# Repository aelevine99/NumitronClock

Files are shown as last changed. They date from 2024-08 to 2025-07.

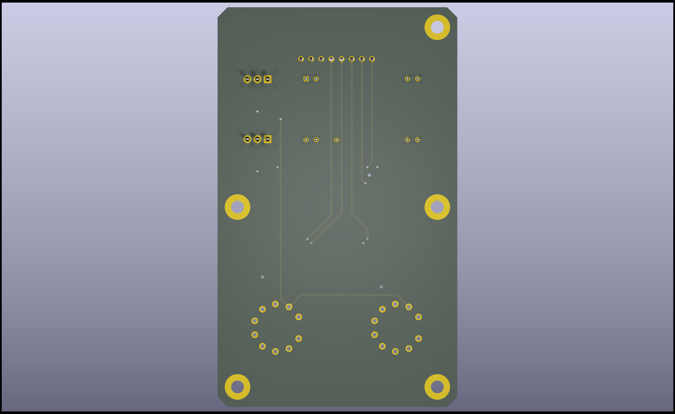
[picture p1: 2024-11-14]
numitron breakout/render_bot.png

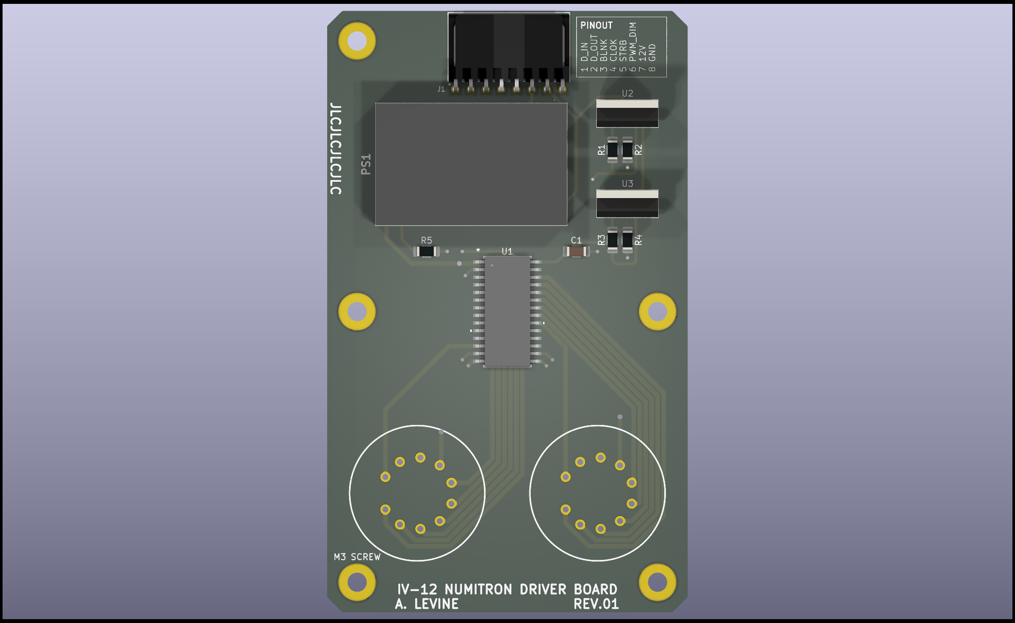
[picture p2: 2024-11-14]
numitron breakout/render_top.png

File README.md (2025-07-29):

# NumitronClock

## Project Overview
This project uses soviet IV-12 tubes (they were easier to find than actual Numitrons) for a fun, retro-inspired desk clock. The project is split into two main parts for modularity: a breakout board that can drive 2 tubes, and a control board with 2 outputs for breakout boards. I will update this description and provide documentation as the project evolves.

## NUMITRONS!
Advert for RCA NUMITRON Display Devices.
"Advert for RCA NUMITRON Display Devices". Electronic Design. 22 (12). Hayden: 163. 1974-06-07.

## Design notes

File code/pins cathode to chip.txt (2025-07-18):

---NUMBER TO PIN MAPPING---
Number	P1	P5	P6	P7	P8	P9	P10
1		0	0	1	1	0	0	0
2		1	1	0	1	1	0	0
3		0	1	1	1	1	1	0
4		0	0	1	1	0	1	1
5		0	1	1	0	1	1	1
6		1	1	1	0	1	1	1
7		0	0	1	1	1	0	0
8		1	1	1	1	1	1	1
9		0	1	1	1	1	1	1
0		1	1	1	1	1	0	1
A		1	0	1	1	1	1	1
b		1	1	1	0	0	1	1
C		1	1	0	0	1	0	1
d		1	1	1	1	0	1	0
E		1	1	0	0	1	1	1
F		1	0	0	0	1	1	1

---PIN TO CHIP MAPPING---
Left digit:
Tube	HV5812WG-G
01/e	12/HVOUT11
05/d	11/HVOUT12
06/c	10/HVOUT13
07/b	09/HVOUT14
08/a	08/HVOUT15
09/g	07/HVOUT16
10/f	06/HVOUT17

Right digit:
Tube	HV5812WG-G
01/e	20/HVOUT7
05/d	21/HVOUT6
06/c	22/HVOUT5
07/b	23/HVOUT4
08/a	24/HVOUT3
09/g	25/HVOUT2
10/f	26/HVOUT1

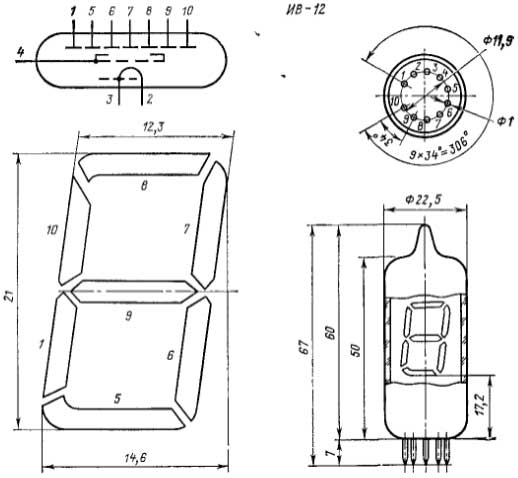
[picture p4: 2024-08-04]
documentation/iv-12 dims.jpg

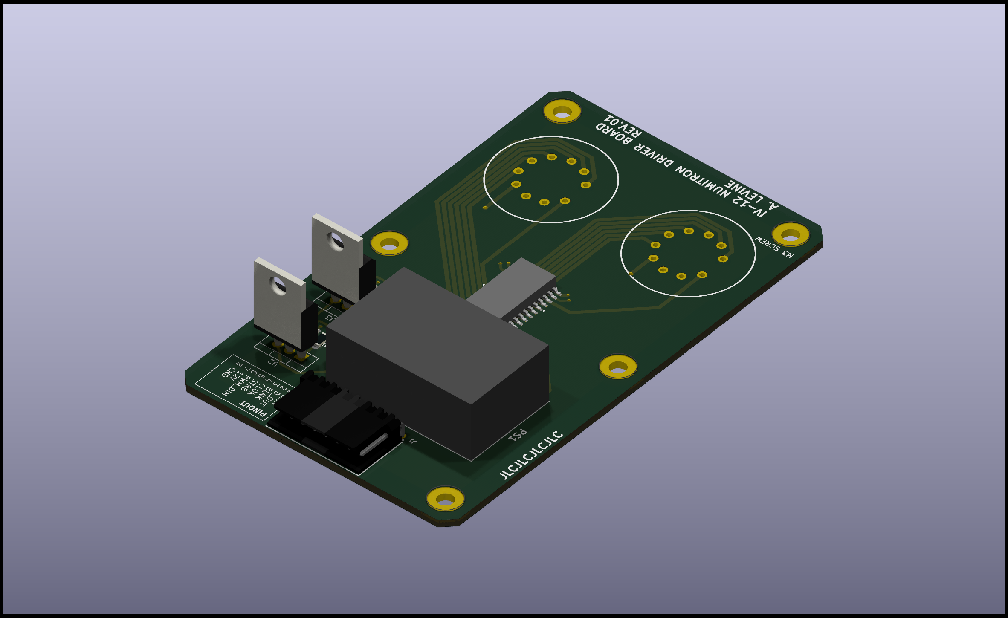
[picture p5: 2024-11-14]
numitron breakout/render_iso3.png

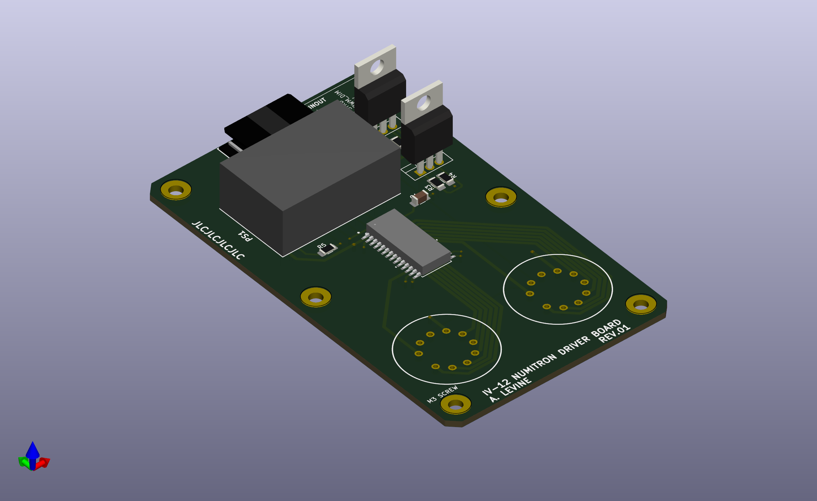
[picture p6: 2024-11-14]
numitron breakout/render_iso2.png

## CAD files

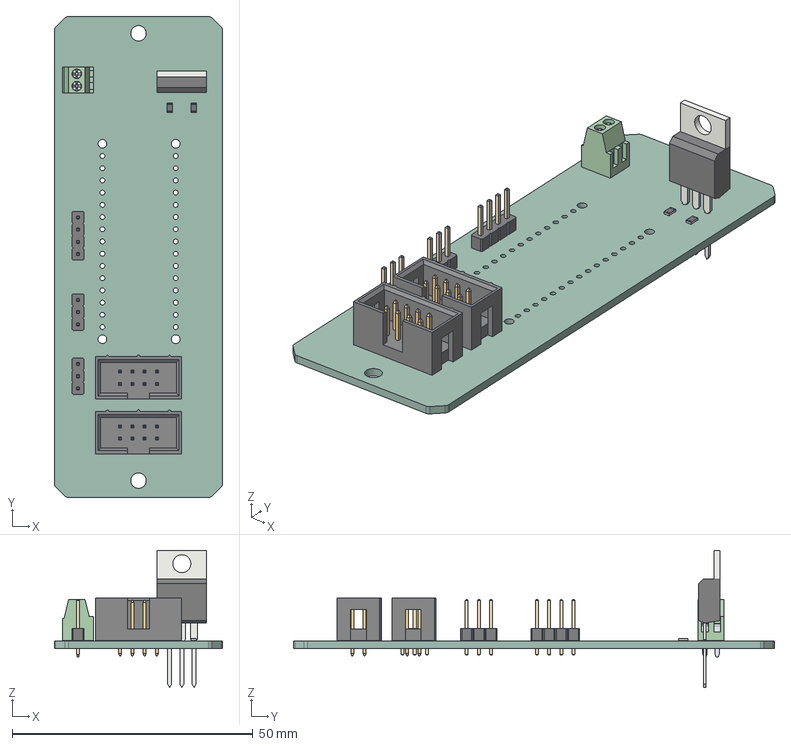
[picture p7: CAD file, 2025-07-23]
controller/numitroncontrol.step
35.0 x 100.0 x 28.5 mm
6120xx21621_PIN x 16
TO-220-3_Vertical
PinHeader_1x04_P2.54mm_Vertical
6912109100xx_CAGE x 2
6912109100xx_PIN x 2
6912109100xx_VIS x 2
R_0805_2012Metric x 2
PinHeader_1x03_P2.54mm_Vertical x 2
numitroncontrol_PCB

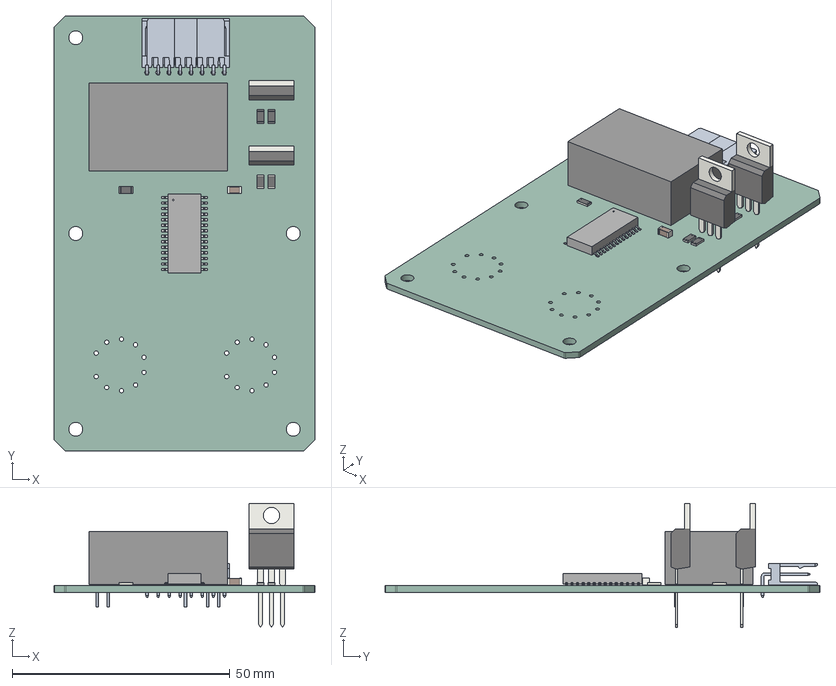
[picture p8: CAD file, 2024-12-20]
numitron breakout/numitronbreakout.step
60.0 x 100.0 x 28.5 mm
C_1206_3216Metric
R_1206_3216Metric x 5
6610xx11722
ASSEMBLY
TO-220-3_Vertical x 2
_autosave-numitronbreakout_PCB

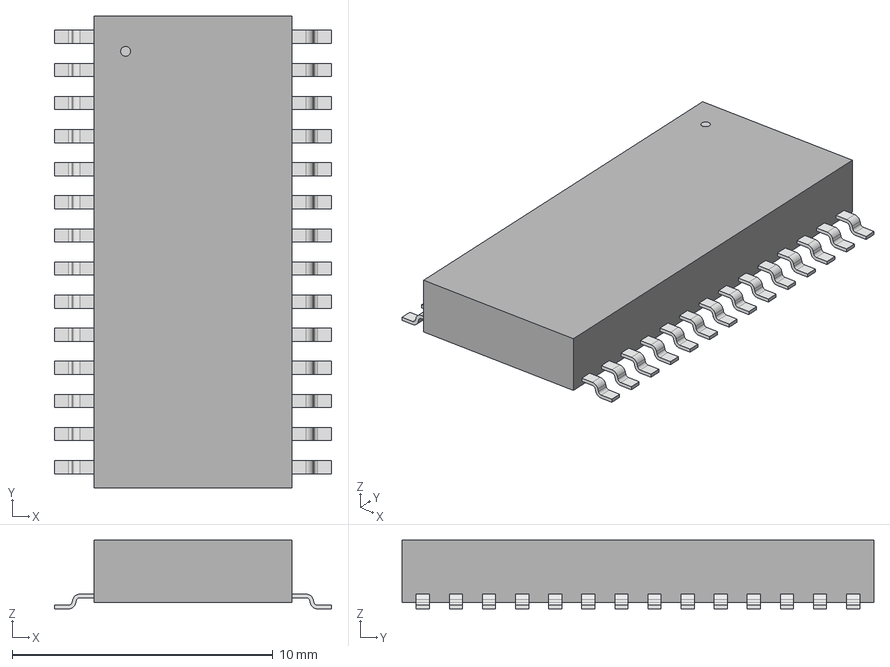
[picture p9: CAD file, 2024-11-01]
numitron breakout/parts/HV5812WG_G/SOW28_17P90X7P50_MCH.step
10.6 x 18.1 x 2.64 mm

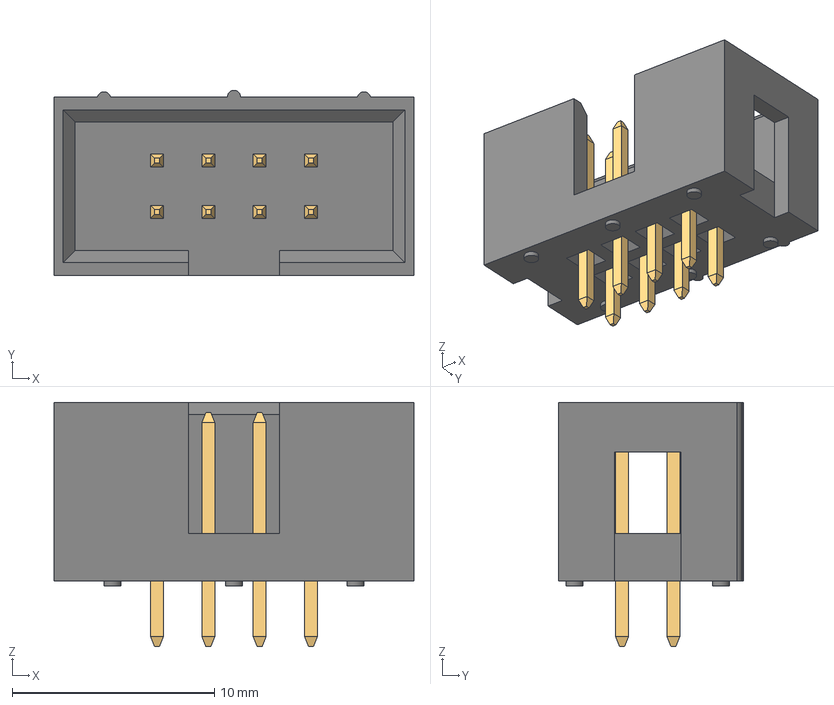
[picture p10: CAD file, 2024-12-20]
controller/parts/6120XX21621_61200821621.step
17.8 x 9.18 x 12.1 mm
6120xx21621_PIN x 8

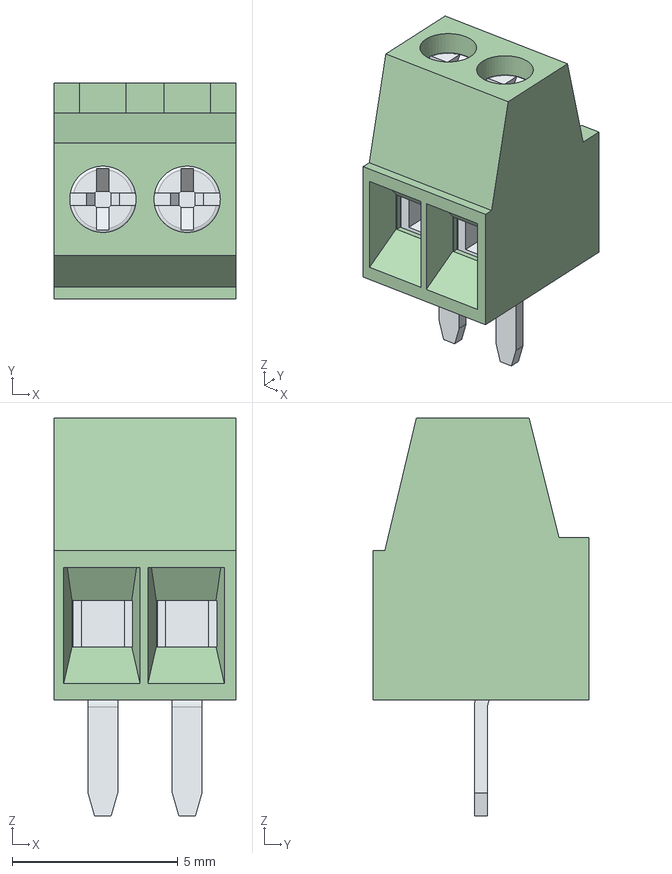
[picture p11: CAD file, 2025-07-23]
controller/parts/691210910002+%28rev1%29.stp
5.48 x 6.50 x 12.0 mm
6912109100xx_CAGE x 2
6912109100xx_PIN x 2
6912109100xx_VIS x 2

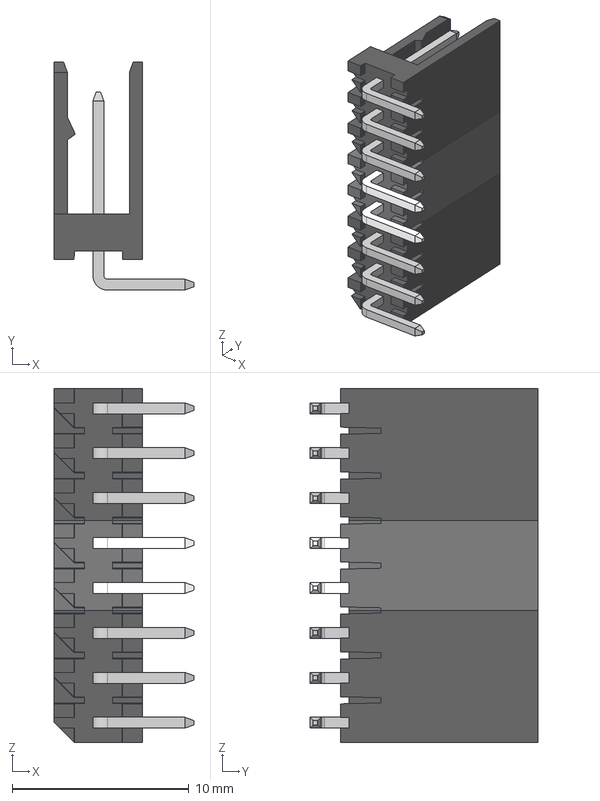
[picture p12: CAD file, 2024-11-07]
numitron breakout/parts/66100811722/66100811722.step
7.90 x 12.9 x 20.0 mm
6610xx11722_07_20_DX
6610xx11722_07_20_SX

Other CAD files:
numitron breakout/parts/LDB-600L/Allegro/ldb600l.psm
numitron breakout/parts/LDB-600L/DEHDL/ldb_600l/chips/chips.prt

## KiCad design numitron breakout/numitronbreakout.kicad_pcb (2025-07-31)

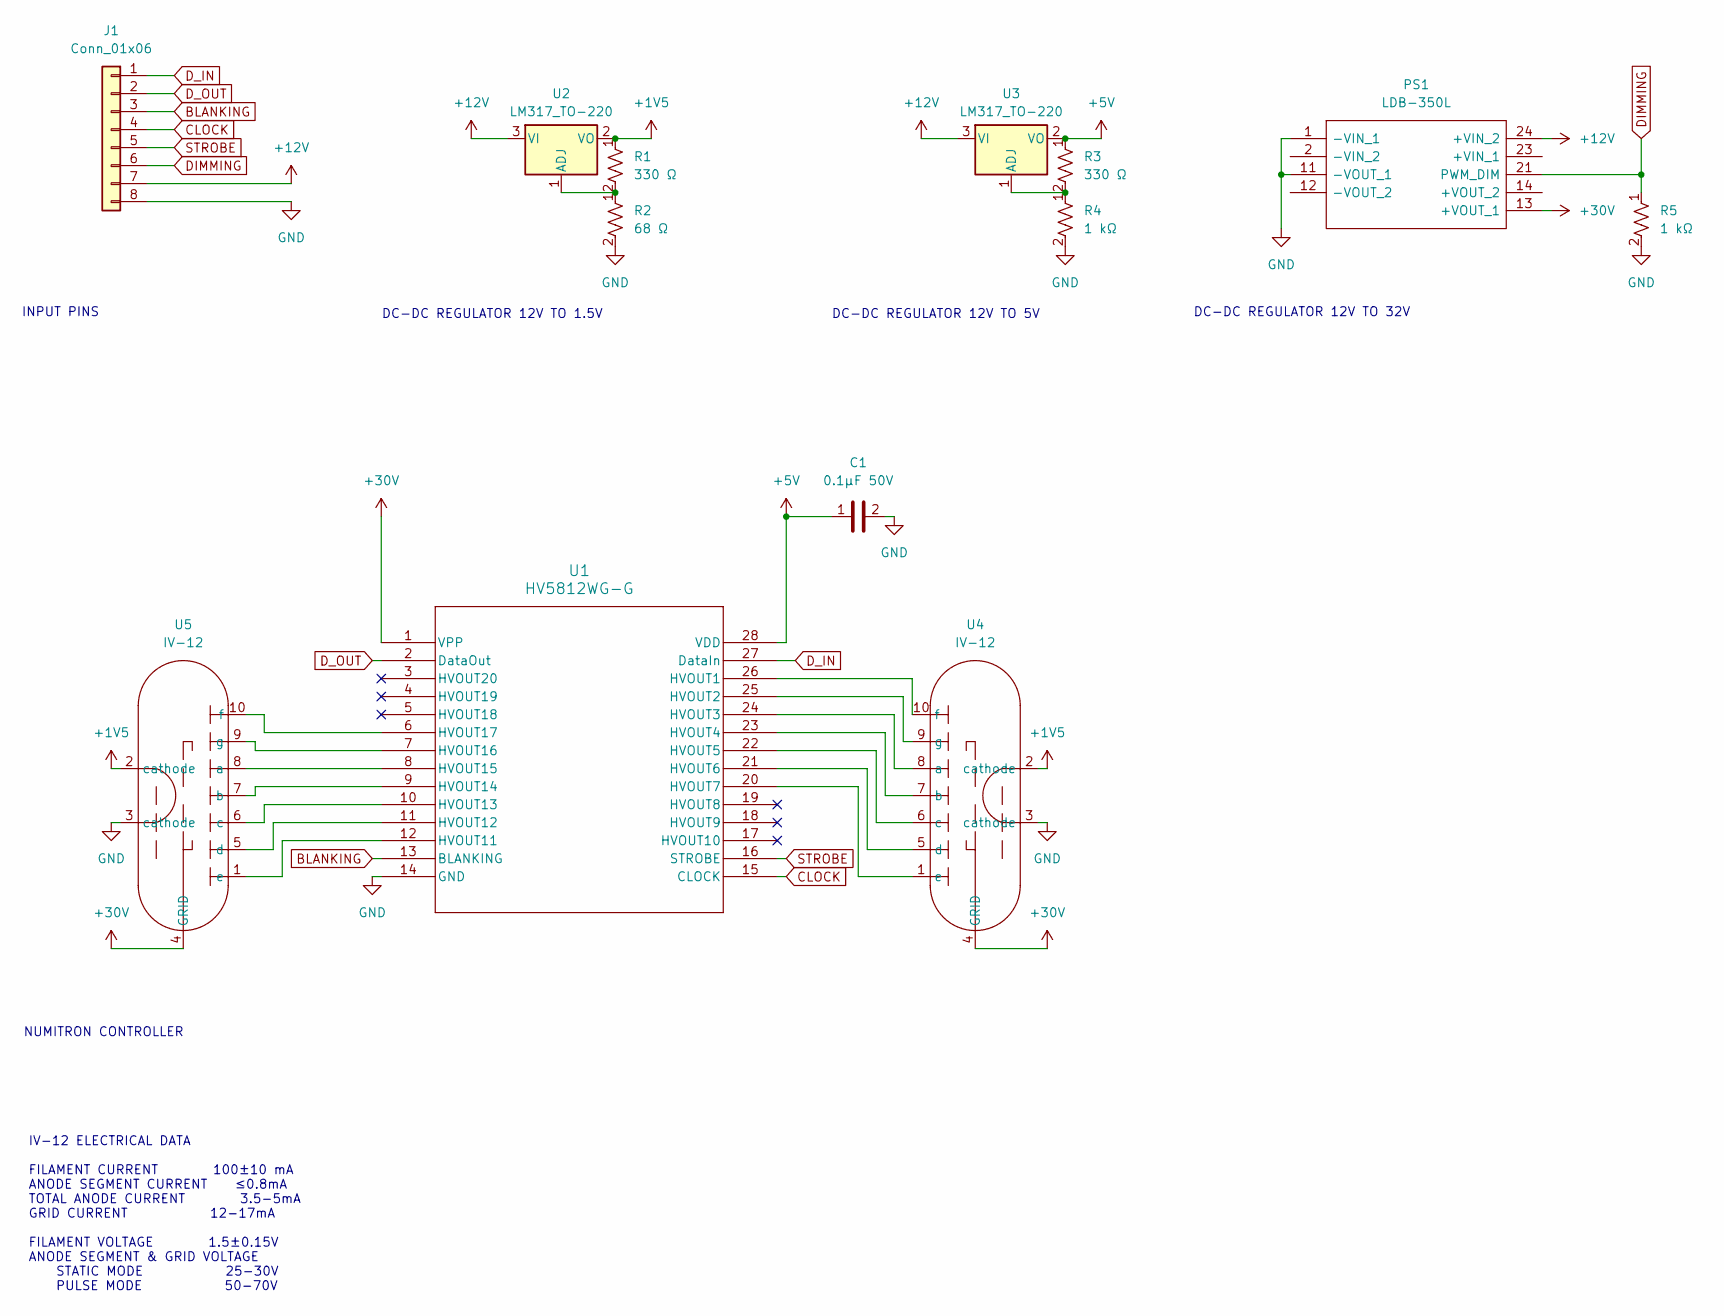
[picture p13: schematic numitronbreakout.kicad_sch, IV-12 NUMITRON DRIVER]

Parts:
C1: 0.1μF 50V; C_1206_3216Metric_Pad1.33x1.80mm_HandSolder; Manufacturer_Part_Number CL31B104KBCNNNC
J1: Conn_01x06; 66100811722; Manufacturer_Part_Number 66100811722
PS1: LDB-350L; LDB600L; Part No LDB-500L
R1, R3: 330 Ω; R_1206_3216Metric_Pad1.30x1.75mm_HandSolder; Part No CRCW0402240RFKED
R2: 68 Ω; R_1206_3216Metric_Pad1.30x1.75mm_HandSolder; Part No CRCW040248R7FKED
R4, R5: 1 kΩ; R_1206_3216Metric_Pad1.30x1.75mm_HandSolder; Part No CRCW040248R7FKED
U1: HV5812WG-G; SOW28_17P90X7P50_MCH; Part No HV5812WG-G
U2, U3: LM317_TO-220; TO-220-3_Vertical; Part No LM317TNS/NOPB-ND
U4, U5: IV-12; iv-12

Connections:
+1V5: R1.1, U2.2 (VO), U4.2 (cathode), U5.2 (cathode)
+5V: C1.1, R3.1, U1.28 (VDD), U3.2 (VO)
+12V: J1.7, PS1.24 (+VIN_2), U2.3 (VI), U3.3 (VI)
+30V: PS1.13 (+VOUT_1), U1.1 (VPP), U4.4 (GRID), U5.4 (GRID)
BLANKING: J1.3, U1.13 (BLANKING)
CLOCK: J1.4, U1.15 (CLOCK)
DIMMING: J1.6, PS1.21 (PWM_DIM), R5.1
D_IN: J1.1, U1.27 (DataIn)
D_OUT: J1.2, U1.2 (DataOut)
GND: C1.2, J1.8, PS1.1 (-VIN_1), PS1.11 (-VOUT_1), R2.2, R4.2, R5.2, U1.14 (GND), U4.3 (cathode), U5.3 (cathode); also elsewhere on the board
unnamed: U1.26 (HVOUT1), U4.10 (f)
unnamed: U1.25 (HVOUT2), U4.9 (g)
unnamed: U1.24 (HVOUT3), U4.8 (a)
unnamed: U1.23 (HVOUT4), U4.7 (b)
unnamed: U1.22 (HVOUT5), U4.6 (c)
unnamed: U1.21 (HVOUT6), U4.5 (d)
unnamed: U1.20 (HVOUT7), U4.1 (e)
unnamed: U1.12 (HVOUT11), U5.1 (e)
unnamed: U1.11 (HVOUT12), U5.5 (d)
unnamed: U1.10 (HVOUT13), U5.6 (c)
unnamed: U1.9 (HVOUT14), U5.7 (b)
unnamed: U1.8 (HVOUT15), U5.8 (a)
unnamed: U1.7 (HVOUT16), U5.9 (g)
unnamed: U1.6 (HVOUT17), U5.10 (f)
unnamed: R1.2, R2.1, U2.1 (ADJ)
unnamed: R3.2, R4.1, U3.1 (ADJ)
STROBE: J1.5, U1.16 (STROBE)

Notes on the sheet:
INPUT PINS
DC-DC REGULATOR 12V TO 1.5V
DC-DC REGULATOR 12V TO 32V
DC-DC REGULATOR 12V TO 5V
NUMITRON CONTROLLER
IV-12 ELECTRICAL DATA FILAMENT CURRENT 100±10 mA ANODE SEGMENT CURRENT ≤0.8mA TOTAL ANODE CURRENT 3.5-5mA GRID CURRENT 12-17mA FILAMENT VOLTAGE 1.5±0.15V ANODE SEGMENT & GRID VOLTAGE STATIC MODE 25-30V PULSE MODE 50-70V

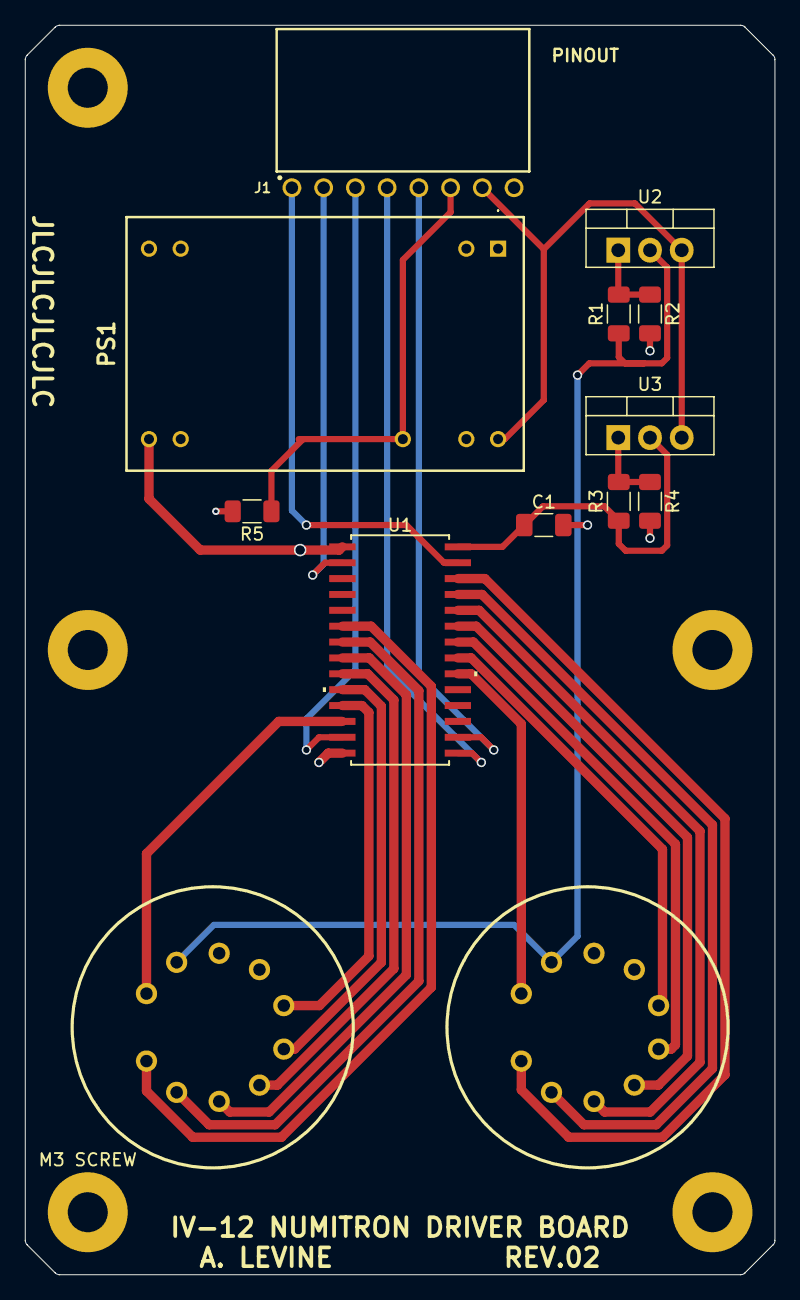
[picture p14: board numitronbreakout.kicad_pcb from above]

Board: 4 copper layers, 60.0 x 100.0 mm, 14 parts (0 on the bottom side), 27 nets.

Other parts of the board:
M3 SCREW: MountingHole_3.2mm_M3_Pad

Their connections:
GND: M3 SCREW.1; also elsewhere on the board

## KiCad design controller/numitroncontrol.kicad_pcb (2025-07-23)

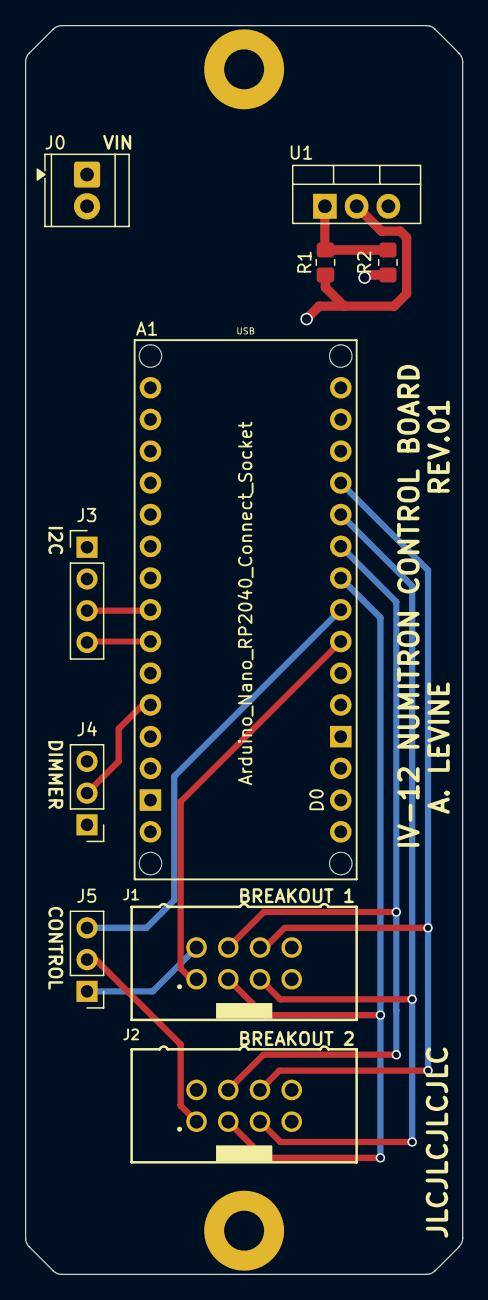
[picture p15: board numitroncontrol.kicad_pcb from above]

Board: 4 copper layers, 35.0 x 100.0 mm, 10 parts (0 on the bottom side), 16 nets.

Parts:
A1: Arduino_Nano_RP2040_Connect_Socket; Arduino_Nano_Every_Socket
J0: Screw_Terminal_01x02; TerminalBlock_TE_282834-2_1x02_P2.54mm_Horizontal
J1, J2: Conn_01x06; 61200821621
J3: I2C; PinHeader_1x04_P2.54mm_Vertical
J4: Screw_Terminal_01x03; PinHeader_1x03_P2.54mm_Vertical
J5: Conn_01x03_Pin; PinHeader_1x03_P2.54mm_Vertical
R1: 390 Ω; R_0805_2012Metric_Pad1.20x1.40mm_HandSolder
R2: 3.3 kΩ; R_0805_2012Metric_Pad1.20x1.40mm_HandSolder
U1: LM317_TO-220; TO-220-3_Vertical

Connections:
+3V3: A1.3V3 (3.3V), J3.2, J4.3
+12V: A1.VIN, J1.7, J2.7, R1.1, U1.2 (VO)
BLANKING: A1.D6, J1.3, J2.3
CLOCK: A1.D7, J1.4, J2.4
DIMMING: A1.D9, J1.6, J2.6
D_IN1: A1.D4, J1.1
D_IN2: A1.D5, J5.3
D_OUT1: J1.2, J5.1
GND: A1.GND1 (GND), A1.GND2 (GND), J0.2, J1.8, J2.8, J3.1, J4.1, R2.2
unnamed: J0.1, U1.3 (VI)
unnamed: J2.1, J5.2
unnamed: R1.2, R2.1, U1.1 (ADJ)
POT: A1.A7, J4.2
SCL: A1.A5 (A5/SCL), J3.4
SDA: A1.A4 (A4/SDA), J3.3
STROBE: A1.D8, J1.5, J2.5

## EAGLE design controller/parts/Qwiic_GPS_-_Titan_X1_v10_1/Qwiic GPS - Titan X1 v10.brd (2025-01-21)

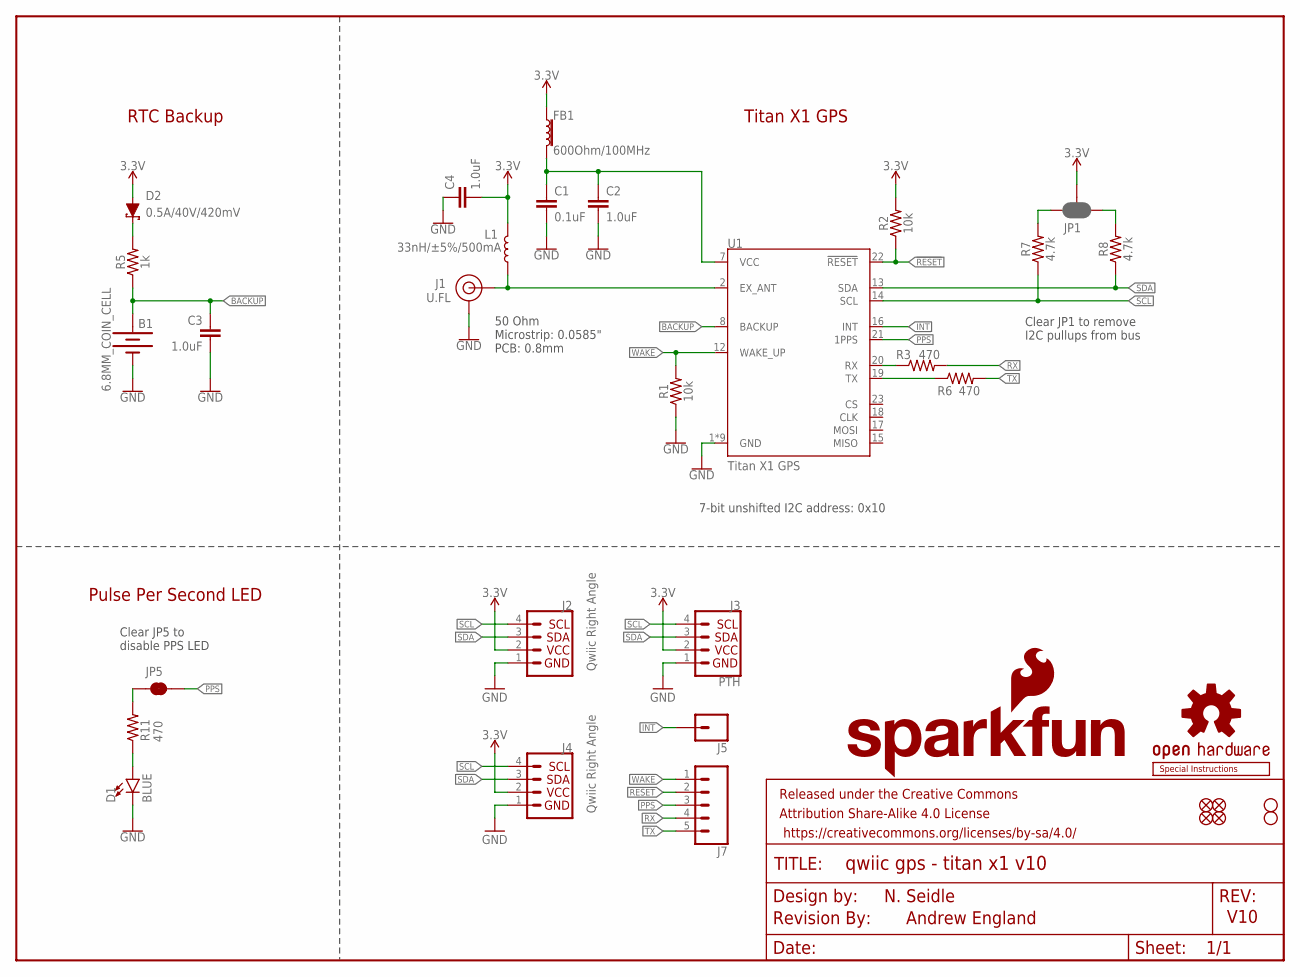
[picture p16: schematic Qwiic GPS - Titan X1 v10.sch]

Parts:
B1: 6.8MM_COIN_CELL; BATTCON-6.8MM
C1: 0.1uF; 0603
C2, C3, C4: 1.0uF; 0603
D1: BLUE; LED-0603
D2: 0.5A/40V/420mV; SOD-323
FB1: 600Ohm/100MHz; 0603
FRAME1: FRAME-LETTER; CREATIVE_COMMONS
J1: U.FL
J2, J4: Qwiic Right Angle; 1X04_1MM_RA
J3: PTH; 1X04_NO_SILK
J5: CONN_01PTH_NO_SILK_YES_STOP; 1X01_NO_SILK
J7: CONN_05NO_SILK; 1X05_NO_SILK
JP1: JUMPER-SMT_3_2-NC_PASTE_SILK; SMT-JUMPER_3_2-NC_PASTE_SILK
JP2, JP6, JP7, JP8: FIDUCIALUFIDUCIAL; MICRO-FIDUCIAL
JP3, JP4: STAND-OFF
JP5: JUMPER-SMT_2_NC_TRACE_NO-SILK; SMT-JUMPER_2_NC_TRACE_NO-SILK
L1: 33nH/±5%/500mA; 0603
LOGO1: OSHW-LOGOMINI; OSHW-LOGO-MINI
LOGO2: SFE_LOGO_NAME_FLAME.1_INCH; SFE_LOGO_NAME_FLAME_.1
LOGO3: REVISION
R1, R2: 10k; 0603
R3, R6, R11: 470; 0603
R5: 1k; 0603
R7, R8: 4.7k; 0603
U1: Titan X1 GPS; TITAN_X1_GPS
U$3: SPECIAL_INSTRUCTIONS-PRODUCTION; PRODUCTION_INSTRUCTIONS

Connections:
3.3V: C4.2, D2.A, FB1.1, J2.2, J3.2 (VCC), J4.2, JP1.2, L1.2, R2.2
!RESET: J7.2, R2.1, U1.22 (!RESET)
BACKUP: B1.+, C3.1, R5.1, U1.8 (BACKUP)
EXT_ANT: J1.FEED (SIGNAL), L1.1, U1.2 (EX_ANT)
GND: B1.-, C1.2, C2.2, C3.2, C4.1, D1.C, J1.1 (GND), J1.2 (GND), J2.1, J3.1 (GND), J4.1, R1.1, U1.1 (GND), U1.3 (GND), U1.4 (GND), U1.5 (GND), U1.6 (GND), U1.9 (GND), U1.10 (GND), U1.11 (GND), U1.24 (GND)
INT: J5.1, U1.16 (INT)
unnamed: D1.A, R11.1
unnamed: JP5.1, R11.2
unnamed: JP1.1, R8.2
unnamed: D2.C, R5.2
unnamed: JP1.3, R7.2
PPS: J7.3, JP5.2, U1.21 (1PPS)
RX: J7.4, R3.2
RXLV: R3.1, U1.20 (RX)
SCL: J2.4, J3.4 (SCL), J4.4, R7.1, U1.14 (SCL)
SDA: J2.3, J3.3 (SDA), J4.3, R8.1, U1.13 (SDA)
TX: J7.5, R6.2
TXLV: R6.1, U1.19 (TX)
VCC_FILTERED: C1.1, C2.1, FB1.2, U1.7 (VCC)
WAKE: J7.1, R1.2, U1.12 (WAKE_UP)

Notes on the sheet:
N. Seidle
V10
7-bit unshifted I2C address: 0x10
Titan X1 GPS
RTC Backup
Pulse Per Second LED
50 Ohm Microstrip: 0.0585" PCB: 0.8mm
Andrew England
Clear JP1 to remove I2C pullups from bus
Clear JP5 to disable PPS LED

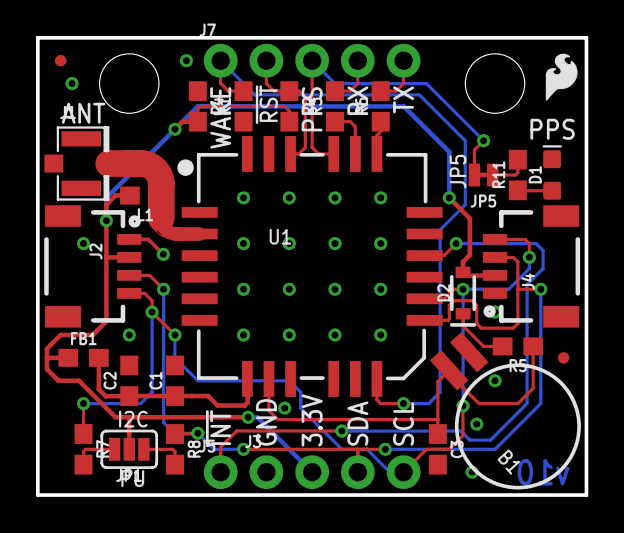
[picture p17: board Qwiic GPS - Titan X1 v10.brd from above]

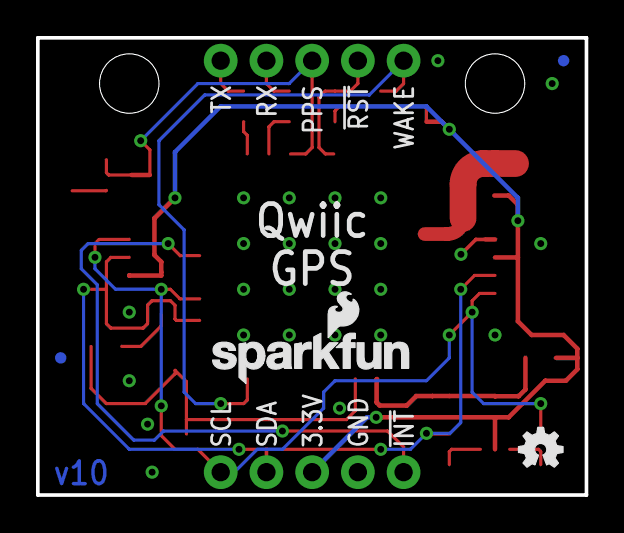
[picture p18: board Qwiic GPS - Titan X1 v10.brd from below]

Board: 2 copper layers, 30.5 x 25.4 mm, 38 parts (4 on the bottom side), 20 nets.

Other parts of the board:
U$2: SFE_LOGO_FLAME_.1

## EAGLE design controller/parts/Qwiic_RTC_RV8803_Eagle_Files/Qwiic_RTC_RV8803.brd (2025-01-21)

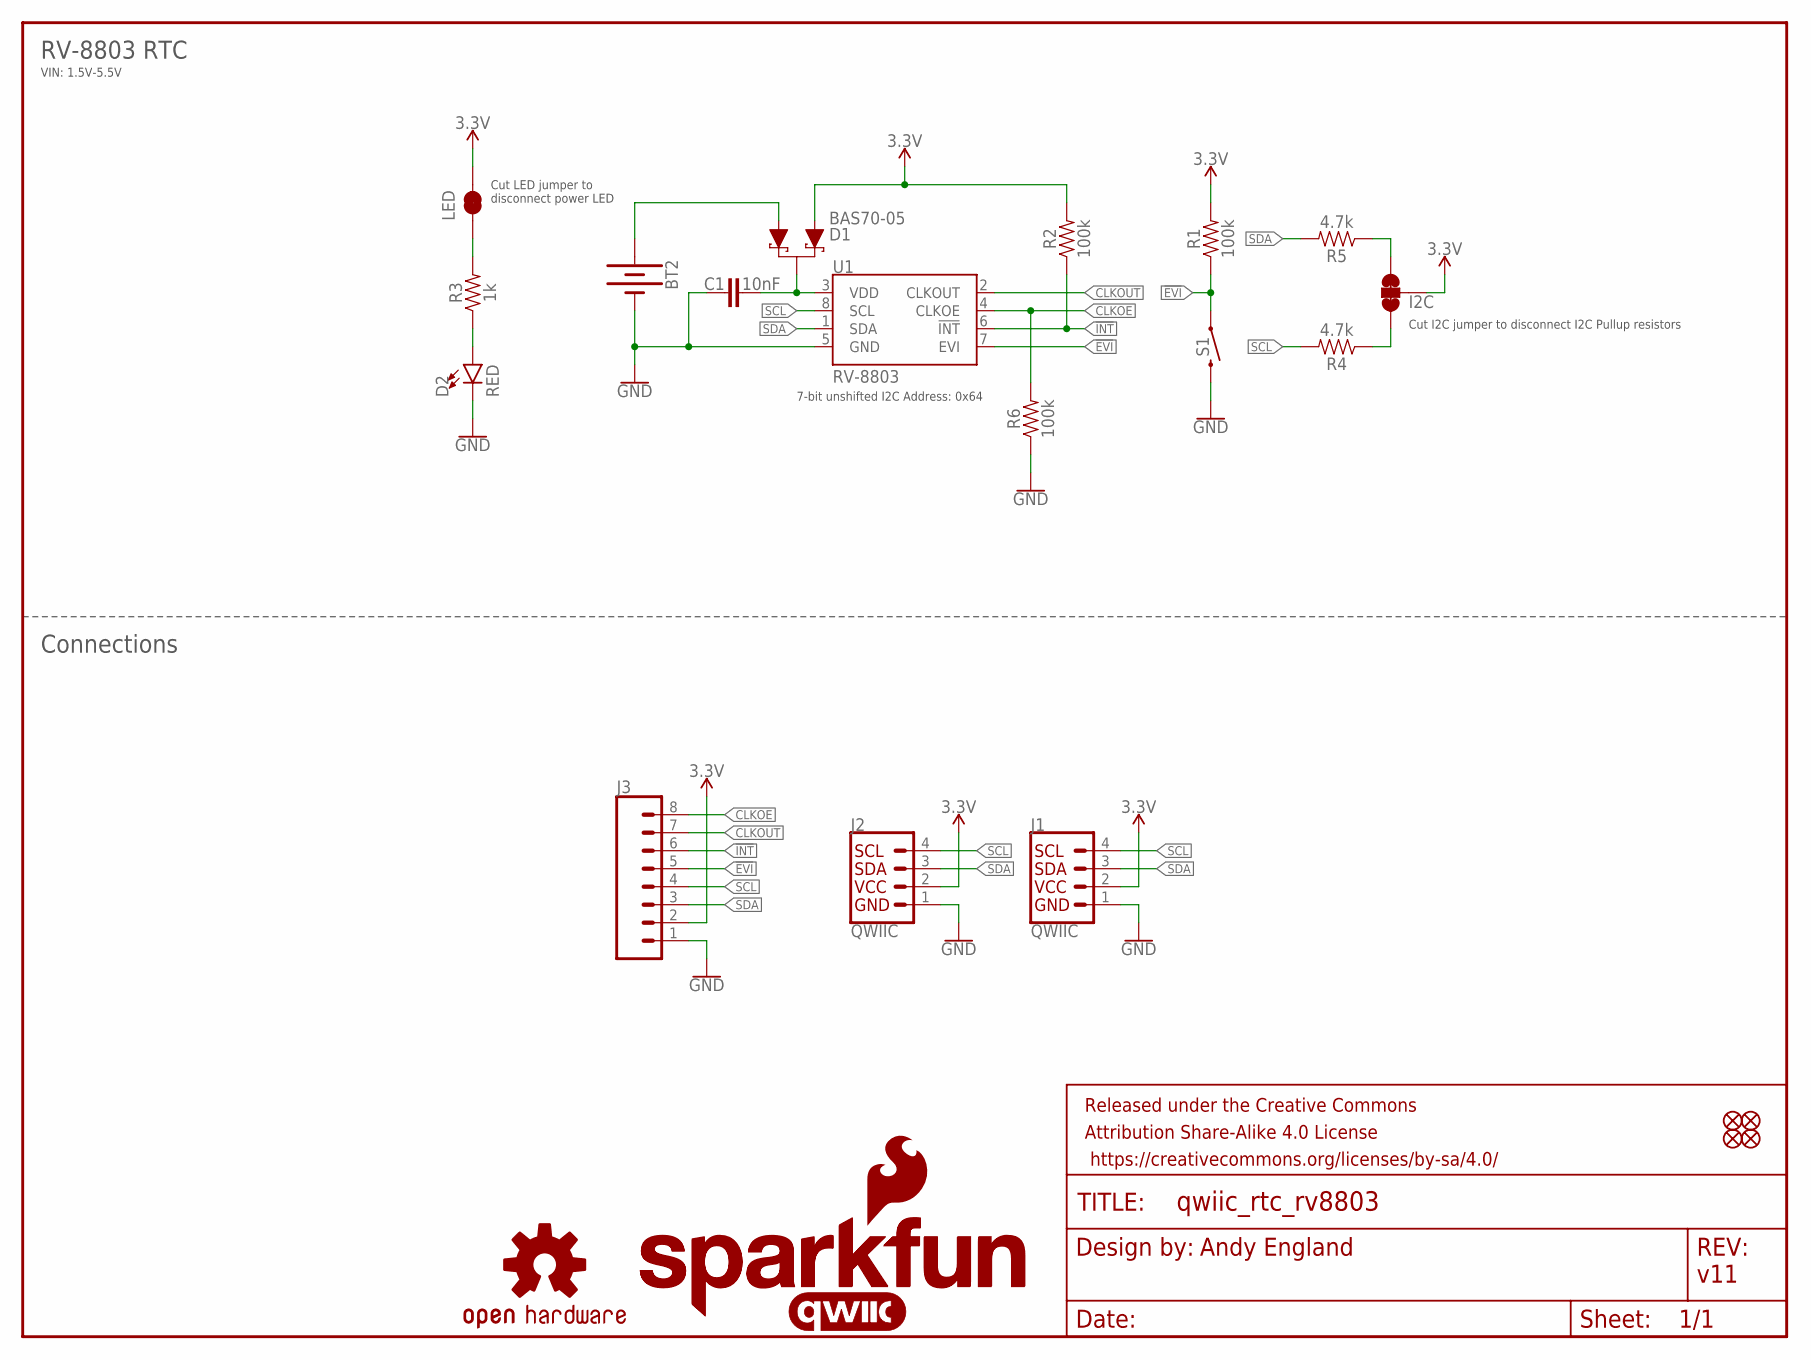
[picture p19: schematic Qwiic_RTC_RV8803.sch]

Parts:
BT2: BATTERY-12MM_SMD; BATTCON_12MM
C1: 10nF; 0603
D1: BAS70-05; SOT23-3
D2: RED; LED-0603
FD1, FD2, FD3, FD4: FIDUCIALUFIDUCIAL; FIDUCIAL-MICRO
FRAME1: FRAME-LETTER; CREATIVE_COMMONS
I2C: JUMPER-SMT_3_2-NC_TRACE_NO-SILK; SMT-JUMPER_3_2-NC_TRACE_NO-SILK
J1, J2: QWIIC; JST04_1MM_RA
J3: CONN_08NO_SILK_FEMALE_PTH; 1X08_NO_SILK
LED: JUMPER-SMT_2_NC_TRACE_NO-SILK; SMT-JUMPER_2_NC_TRACE_NO-SILK
LOGO1: SFE_LOGO_NAME_FLAME.1_INCH; SFE_LOGO_NAME_FLAME_.1
LOGO2: OSHW-LOGOS; OSHW-LOGO-S
LOGO4: QWIIC_LOGO_5MM; QWIIC_5MM
LOGO5: SFE_LOGO_NAME.1_INCH; SFE_LOGO_NAME_.1
R1, R2, R6: 100k; 0603
R3: 1k; 0603
R4, R5: 4.7k; 0603
S1: MOMENTARY-SWITCH-SPST-SMD-5.2MM-TALL; TACTILE_SWITCH_SMD_5.2MM
U1: RV-8803; RV-3028

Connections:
3.3V: D1.1 (A), I2C.2, J1.2, J2.2, J3.2, LED.2, R1.2, R2.2
!EVI: J3.5, R1.1, S1.1, U1.7 (EVI)
!INT: J3.6, R2.1, U1.6 (!INT)
CLKOE: J3.8, R6.2, U1.4 (CLKOE)
CLKOUT: J3.7, U1.2 (CLKOUT)
GND: BT2.GND (-), C1.1, D2.C, J1.1, J2.1, J3.1, R6.1, S1.3 (2), U1.5 (GND)
unnamed: C1.2, D1.3 (C), U1.3 (VDD)
unnamed: D2.A, R3.1
unnamed: BT2.PWR@1 (+), D1.2 (A1)
unnamed: LED.1, R3.2
unnamed: I2C.3, R5.1
unnamed: I2C.1, R4.1
SCL: J1.4, J2.4, J3.4, R4.2, U1.8 (SCL)
SDA: J1.3, J2.3, J3.3, R5.2, U1.1 (SDA)

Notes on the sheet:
Andy England
v11
Connections
RV-8803 RTC
VIN: 1.5V-5.5V
Cut I2C jumper to disconnect I2C Pullup resistors
Cut LED jumper to disconnect power LED
7-bit unshifted I2C Address: 0x64

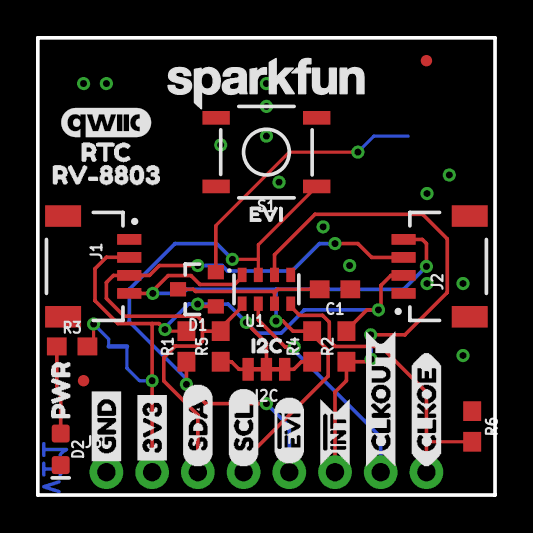
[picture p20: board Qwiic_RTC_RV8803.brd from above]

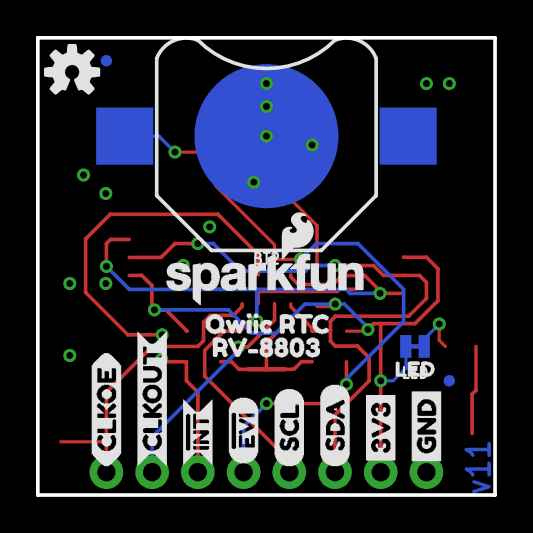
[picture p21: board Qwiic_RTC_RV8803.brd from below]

Board: 2 copper layers, 25.4 x 25.4 mm, 50 parts (17 on the bottom side), 14 nets.

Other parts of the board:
U$1, U$2: 3V31
U$3, U$4: GND0
U$5, U$6: SDA2
U$7, U$8: SCL3
U$9, U$10: #EVI2
U$11, U$12: CLKOUT6
U$13, U$14: CLKOE7
U$15, U$16: #INT5
U$17: PWR7
U$18: EVI1
U$19: I2C0
U$20: LED2
U$21: QWIIC_RTC0
U$22, U$24: _RV#88031
U$25: RTC0

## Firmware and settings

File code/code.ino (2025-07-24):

/*

Control for Nixie Clock
Al Levine

*/

// ~~~~~~~~~~~~~~~~~~~~ LIBRARY IMPORTS ~~~~~~~~~~~~~~~~~~~~
#include <Wire.h>  // i2c library				https://docs.arduino.cc/language-reference/en/functions/communication/wire/

// ~~~~~~~~~~~~~~~~~~~~ HARDWARE PIN DEFINITIONS ~~~~~~~~~~~~~~~~~~~~
// use const instead of define https://docs.arduino.cc/language-reference/en/variables/variable-scope-qualifiers/const/
const int SCL = 5;   // ANALOG PIN i2c SCL
const int SDA = 4;   // ANALOG PIN i2c SDA
const int DIN1 = 4;  // HV8512 serial data input for 1st chip
const int DIN2 = 5;  // HV8512 serial data input for 2nd chip IF board is set to discrete
const int BLK = 6;   // HV5812 blanking input
const int CLK = 7;   // HV5812 data shift register clock input
const int STR = 8;   // HV5812 output enable input
const int DIM = 9;   // Dimming PWM
const int POT = 7;   // Potentiometer input

// Assignment of tube cathodes to HV8512 driver pins
/*
Left digit:					Right digit:
Tube	HV5812WG-G			Tube	HV5812WG-G
01/e	12/HVOUT11			01/e	20/HVOUT7
05/d	11/HVOUT12			05/d	21/HVOUT6
06/c	10/HVOUT13			06/c	22/HVOUT5
07/b	09/HVOUT14			07/b	23/HVOUT4
08/a	08/HVOUT15			08/a	24/HVOUT3
09/g	07/HVOUT16			09/g	25/HVOUT2
10/f	06/HVOUT17			10/f	26/HVOUT1
*/

//	cathode	 		01, 05, 06, 07, 08, 09, 10
const int tube1[7] = { 11, 12, 13, 14, 15, 16, 17 };  // assuming hvout number and not actual pin????
const int tube2[7] = { 7, 6, 5, 4, 3, 2, 1 };
const int tube3[7] = { 31, 32, 33, 34, 35, 36, 37 };  // add 20 for tube 1 second chip
const int tube4[7] = { 17, 16, 15, 14, 13, 12, 11 };  // add 20 for tube 2 second chip

// ~~~~~~~~~~~~~~~~~~~~ MISC SETUP ~~~~~~~~~~~~~~~~~~~~

int displayBuffer[40];   // Bit array for 2x HV5812 chips
int digits[4] = { 0, 0, 0, 0 };  // array to store digits

// Font table
//	tube pin   1,5,6,7,8,9,10
const int num0[7] = { 1, 1, 1, 1, 1, 0, 1 };
const int num1[7] = { 0, 0, 1, 1, 0, 0, 0 };
const int num2[7] = { 1, 1, 0, 1, 1, 0, 0 };
const int num3[7] = { 0, 1, 1, 1, 1, 1, 0 };
const int num4[7] = { 0, 0, 1, 1, 0, 1, 1 };
const int num5[7] = { 0, 1, 1, 0, 1, 1, 1 };
const int num6[7] = { 1, 1, 1, 0, 1, 1, 1 };
const int num7[7] = { 0, 0, 1, 1, 1, 0, 0 };
const int num8[7] = { 1, 1, 1, 1, 1, 1, 1 };
const int num9[7] = { 0, 1, 1, 1, 1, 1, 1 };

// ~~~~~~~~~~~~~~~~~~~~ SETUP FUNCTION ~~~~~~~~~~~~~~~~~~~~

void setup() {
	Serial.begin(9600);  //intialize serial output

	// initialize output pins
	pinMode(DIN1, OUTPUT);
	digitalWrite(DIN1, LOW);
	pinMode(BLK, OUTPUT);
	digitalWrite(BLK, LOW);
	pinMode(CLK, OUTPUT);
	digitalWrite(CLK, LOW);
	pinMode(STR, OUTPUT);
	digitalWrite(STR, LOW);
	pinMode(DIM, OUTPUT);
	digitalWrite(DIM, LOW);
}

// ~~~~~~~~~~~~~~~~~~~~ LOOP FUNCTION ~~~~~~~~~~~~~~~~~~~~

void loop() {
}

// ~~~~~~~~~~~~~~~~~~~~ OTHER FUNCTIONS ~~~~~~~~~~~~~~~~~~~~

void printNum(int *buffer, int tube[7], int num[7]) {  //writes font table values by tube pins into display buffer
	for (int i = 0; i < 7; i++) {
		int pos = tube[i];     // get pin number from tube pin assignment array
		buffer[pos] = num[i];  // write value from font table to relevant pin in display buffer
	}
}

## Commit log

2024-08-04 added tube, shift register
    [kicad.kicad_sch, untitled.kicad_sch]
2024-08-05 added controller
    [kicad.kicad_sch, untitled.kicad_sch]
2024-09-01 shift register wiring cleanup
    [kicad.kicad_sch, numitron_control.kicad_sch, untitled.kicad_sch]
2024-09-03 added voltage regulators, changed bit register
    [kicad.kicad_sch, numitron_control.kicad_sch]
2024-09-06 Updated driver breakout and selected boost IC
    [kicad.kicad_sch]
2024-09-09 boost converter circuit populated, simplified wiring
    [boost.kicad_sch, numitronbreakout.kicad_pcb, numitronbreakout.kicad_sch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]
2024-09-10 library cleanup
    [boost.kicad_sch, numitronbreakout.kicad_sch]
2024-09-10 began pcb layout
    [boost.kicad_sch, numitronbreakout.kicad_pcb, numitronbreakout.kicad_sch]
2024-10-28 boost converter refactor
    new design from web bench to reduce bom complexity & increase efficiency
    [boost.kicad_sch, numitronbreakout.kicad_pcb, numitronbreakout.kicad_sch]
2024-10-28 pcb layout
    [numitronbreakout.kicad_pcb, numitronbreakout.kicad_sch, stepup.kicad_sch]
2024-10-31 finished wiring everything but 30v
    [numitronbreakout.kicad_pcb, numitronbreakout.kicad_sch, stepup.kicad_sch]
2024-11-01 finally decided v boost solution, finished pathing pcb
    [EDI2CAP.CFG, LDB-600L.SchLib, LDB-600L.stp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]
2024-11-01 increased resistor size, generated gerbers for fab
    [boost.kicad_sch, numitronbreakout.kicad_pcb, numitronbreakout.kicad_sch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]
2024-11-07 updated pin connector, layout
    [66100811722.step, numitronbreakout.kicad_pcb, numitronbreakout.kicad_sch]
2024-11-07 fixed 3d model
    [numitronbreakout.kicad_pcb]
2024-11-12 updated boost converter and added dimming capability
    [numitronbreakout.kicad_pcb, numitronbreakout.kicad_sch]
2024-11-12 added mounting holes
    [numitron_control.kicad_sch, numitronbreakout.kicad_pcb]
2024-11-12 grounded mounting holes
    [numitronbreakout.kicad_pcb]
2024-11-12 Small routing fix
    [numitronbreakout.kicad_pcb]
2024-11-12 gerber update
2024-11-13 started controller schematic
    [66100811722.step, EDI2CAP.CFG, LDB-600L.SchLib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]
2024-11-14 updated trace widths and did some renders
    [numitronbreakout.kicad_pcb]
2024-11-16 minor pcb layout updates
    [numitronbreakout.kicad_pcb]
2024-11-19 arduino pinout
    [numitroncontrol.kicad_sch]
2024-12-13 updated power supply
    [numitronbreakout.kicad_pcb, numitronbreakout.kicad_sch]
2024-12-20 continued design work on controller
    [6120XX21621_61200821621.step, numitronbreakout.step, numitroncontrol.kicad_sch]
2025-01-20 finished controller schematic, started pcb
    [ChronoDotV2.brd, ChronoDotV2.sch, numitroncontrol.kicad_pcb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]
2025-01-21 control pcb finished
    [ChronoDotV2.brd, ChronoDotV2.sch, Qwiic GPS - Titan X1 v10.brd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]
2025-01-21 control pcb edits
    [numitroncontrol.kicad_pcb]
2025-01-21 production files
    [numitroncontrol.kicad_pcb]
2025-01-21 played tetris on pcb and re-exported prod files
    [numitroncontrol.kicad_pcb, numitroncontrol.kicad_sch]
2025-01-21 more pcb edits
    [numitroncontrol.kicad_pcb, numitroncontrol.step]
2025-02-03 fixed serial communication pins
    [numitroncontrol.kicad_pcb, numitroncontrol.kicad_sch]
2025-02-03 pin mapping
2025-07-12 updated control board
    [numitronbreakout.kicad_pcb, numitroncontrol.kicad_pcb, numitroncontrol.kicad_sch]
2025-07-17 replaced pot with screw terminal for flexible mounting
    [numitroncontrol.kicad_pcb, numitroncontrol.kicad_sch]
2025-07-18 code attempt, small layout updates
    [numitronbreakout.kicad_sch, numitroncontrol.kicad_pcb, numitroncontrol.kicad_sch]
2025-07-22 Added jumper for control schemes
    can have discrete or daisy control of second output on control board
    [numitroncontrol.kicad_pcb, numitroncontrol.kicad_sch, numitroncontrol.step]
2025-07-23 control board layout tweaks
    [numitroncontrol.kicad_pcb, numitroncontrol.kicad_sch]
2025-07-23 more controller layout updates
    [691210910002+%28rev1%29.stp, numitroncontrol.kicad_pcb, numitroncontrol.kicad_sch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]
2025-07-23 layout updates, gerbers generated
    [numitroncontrol.kicad_pcb, numitroncontrol.kicad_sch, numitroncontrol.step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]
2025-07-23 gerber fix
    [numitroncontrol.kicad_pcb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]
2025-07-24 code fixes
    I have no idea what I'm doing :)
    [code.ino]
2025-07-24 fixed dimming issue
    dimming pwm signal was connected to the wrong pin (VOUT2 instead of PWM_DIM) on the meanwell power supply.
    [numitronbreakout.kicad_pcb, numitronbreakout.kicad_sch]
2025-07-31 updated breakout board gerbers
    [numitronbreakout.kicad_pcb]

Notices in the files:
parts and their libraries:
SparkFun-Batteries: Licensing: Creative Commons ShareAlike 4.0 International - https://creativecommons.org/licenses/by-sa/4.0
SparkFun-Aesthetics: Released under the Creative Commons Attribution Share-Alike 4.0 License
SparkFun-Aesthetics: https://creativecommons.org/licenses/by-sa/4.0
